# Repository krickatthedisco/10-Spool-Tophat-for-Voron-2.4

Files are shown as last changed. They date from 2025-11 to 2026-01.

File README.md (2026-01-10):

# 10-Spool-Tophat-for-Voron-2.4
This repo contains the model files, BOM, and everything else related to the design and implementation of a top hat for Voron 2.4 (and other printers) to support the Bondtech INDX



Alpha Release:

***Updated Panels, got mine in and the bottom one was a little tight and required slight modification for the joining plates. If you ordered the panels before this update, carefully use a dremel to remove the small piece enclosing each joining plate opening.***

This project is still in development, but I am releasing the fusion file publicly if anyone would like to contribute or fork it for other printers. Enjoy!

Use code:TOPHAT for 5% off your extrusions at Zyltech.com 

***1/10/26 update***, added files "200mm printed tophat.step" and "200mm printed tophat.f3z". These are a printed tophat spacer designed to add extra room for the bowden tubes. Included are front and back panels with holes for M3 heatset inserts and zip ties on the inside, and connector pieces to attach the panels together. You need 8 panels total, export them as you desire with or without the holes for the Creality Chamber Heater: https://www.amazon.com/dp/B0FJS593TQ
If you aren't using the Creality heater, just mirror one of the other front panel pieces in your slicer.
The following hardware is needed:

-M3x6 12pcs

-M3x16 12pcs

-M3 nut 12pcs

-M3 heat set insert 12 pcs

-M5x10 24pcs

-M5 roll in nut OR M5 T-nut 24pcs

-If using Creality heater, M3x8 3pcs

***Recommendations*** 

-Print in ABS or ASA

-Use a wide (10mm+) brim as these are very prone to warping

-No supports are needed

-Carefully remove the mouse ears after printing with a side cutter, do not try to bend them you will rip the bottom layer off the print

-Use 1mm foam tape between the pieces to seal them



BOM: https://docs.google.com/spreadsheets/d/1bkKnmu6Y5YQMKTWtyxwqEnmTFSpr5iOI21mws95jtqQ/edit?usp=sharing

CERN Open Hardware Licence Version 2 - Permissive

Copyright (c) 2025, Tyler Krick

This source describes Open Hardware and is licensed under the CERN-OHL-P v2.

You may redistribute and modify this documentation and make products using it
under the terms of the CERN-OHL-P v2 (https://ohwr.org/project/cernohl/wikis/Documents/CERN-OHL-version-2).
This documentation is distributed WITHOUT ANY EXPRESS OR IMPLIED WARRANTY,
INCLUDING OF MERCHANTABILITY, SATISFACTORY QUALITY AND FITNESS FOR A PARTICULAR PURPOSE.
Please see the CERN-OHL-P v2 for applicable conditions.

Source Location: https://github.com/krickatthedisco/10-Spool-Tophat-for-Voron-2.4/tree/main

As per CERN-OHL-P v2, should you produce hardware based on this documentation,
you must provide a copy of the license text and keep notices of authorship and
attribution intact.

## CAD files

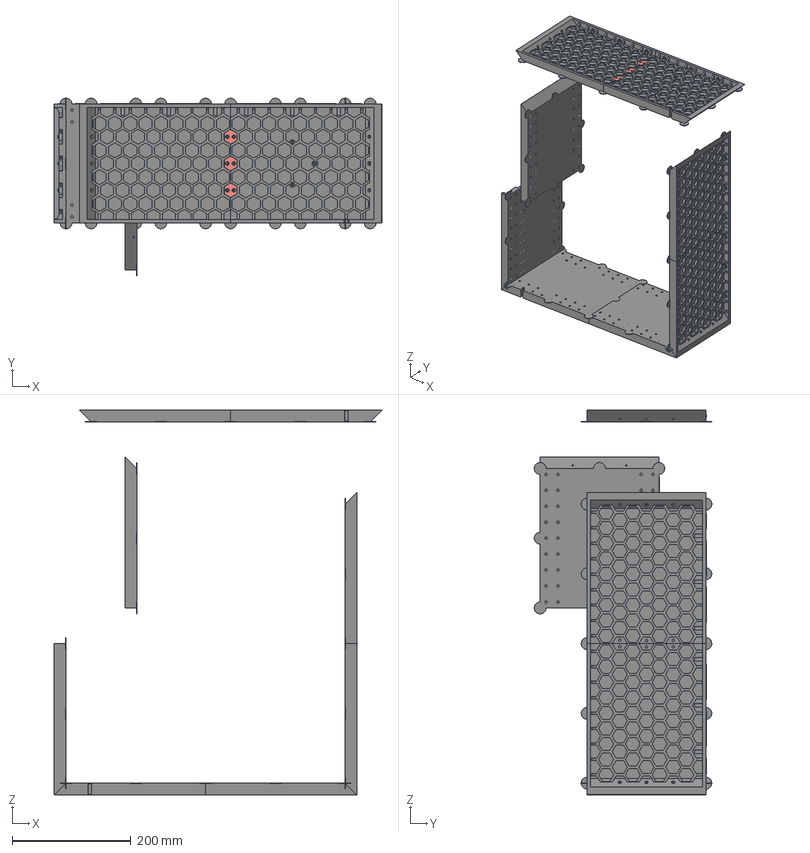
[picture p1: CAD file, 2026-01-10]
200mm printed tophat.step
551.8 x 299.1 x 648.4 mm
Creality Heater Adapted Piece x 2
Connector x12 x 3
200mm printed tophat_side x 2
200mm printed tophat_side v2(Mirror) x 2

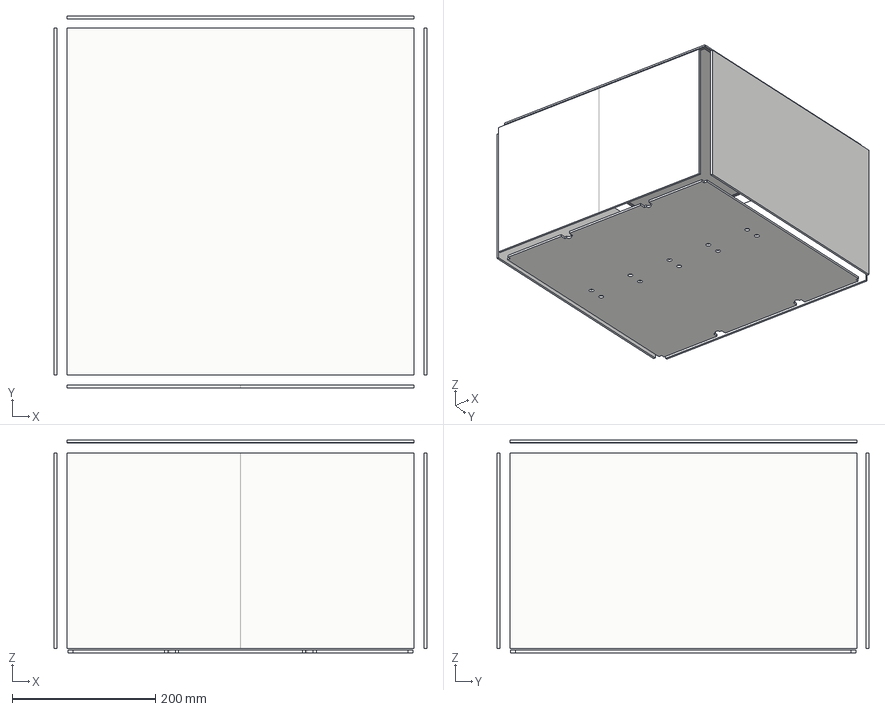
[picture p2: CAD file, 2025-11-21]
Panels.step
520.0 x 519.0 x 297.0 mm
Top Panel
Side Panel x 2
Back Panel
Door x 2
Foam Tape (1mm)
OPTIONAL Bottom Panel

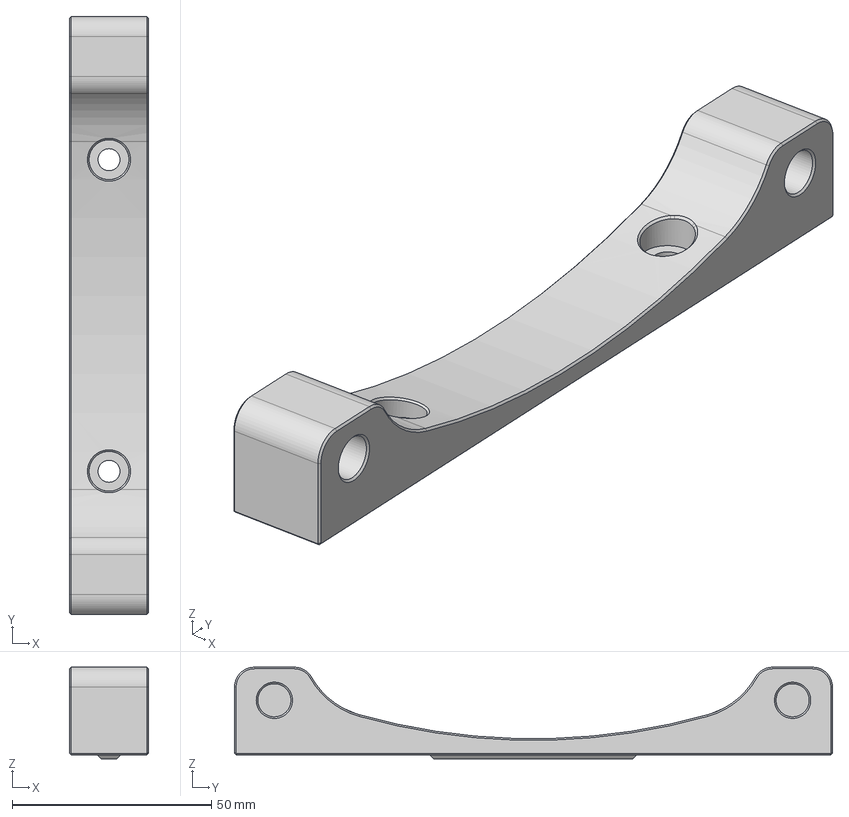
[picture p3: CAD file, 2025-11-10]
spool roller shaft mount.step
19.8 x 150.0 x 23.0 mm

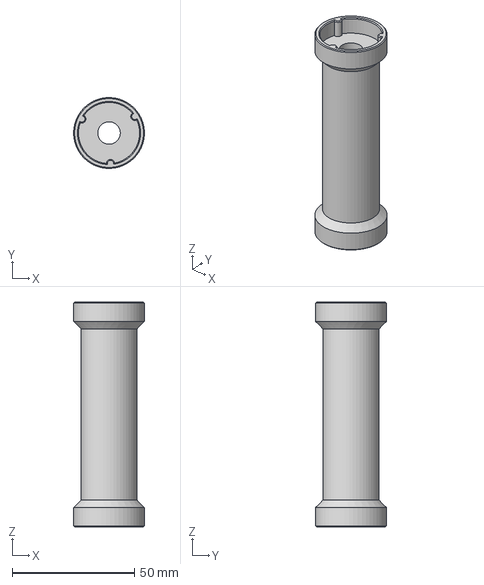
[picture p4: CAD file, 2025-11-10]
spool roller.step
29.0 x 29.0 x 92.0 mm

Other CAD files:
10 Spool Top Hat for Voron 2.4.f3z
200mm printed tophat.f3z
spool roller shaft mount.f3d
spool roller shaft mount.stl
spool roller.f3d
spool roller.stl

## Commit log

2025-11-07 Add files via upload
    updated tolerance to tighten bearing
2025-11-07 Add files via upload
    should be final updated tolerance
    [spool roller.stl]
2025-11-10 Add files via upload
    Alpha Release of the Fusion and STEP files for non-Fusion users. Enjoy!
    [10 Spool Top Hat for Voron 2.4 - Alpha Release.f3z, spool roller shaft mount.f3d, spool roller shaft mount.step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]
2025-11-15 Add files via upload
    fixed back panel dimension
    [10 Spool Top Hat for Voron 2.4.f3z]
